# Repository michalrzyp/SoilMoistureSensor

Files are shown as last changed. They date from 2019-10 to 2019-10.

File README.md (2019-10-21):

# SoilMoistureSensor
The assumption of the project was to create a soil moisture sensor and a station collecting measurement results, 
which by analyzing the received data provides information on the degree of soil moisture. 
The sensor placed in the pot sends information via radio to the base station, which is located anywhere in the apartment / house. 
The sensor measured humidity by measuring its resistance.

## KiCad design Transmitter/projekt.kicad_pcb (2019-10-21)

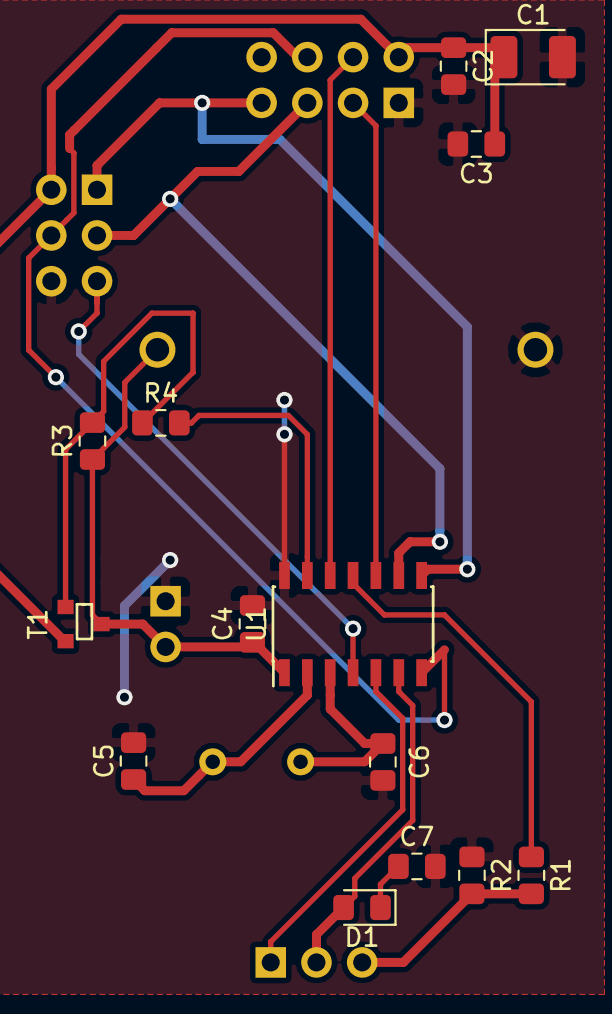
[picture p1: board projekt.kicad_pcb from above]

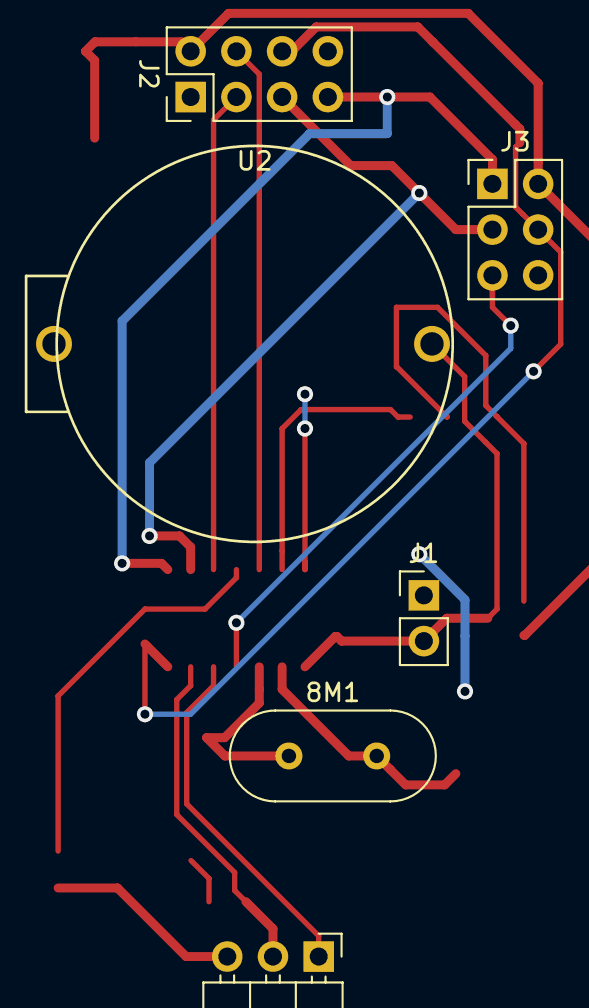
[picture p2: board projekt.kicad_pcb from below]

Board: 2 copper layers, 20 parts (6 on the bottom side), 18 nets.

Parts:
8M1: Crystal_Small; Crystal_HC49-4H_Vertical
C1: 100u; CP_EIA-3528-21_Kemet-B_Pad1.50x2.35mm_HandSolder
C2, C3, C4: 100n; C_0805_2012Metric_Pad1.15x1.40mm_HandSolder
C5, C6, C7: 22p; C_0805_2012Metric_Pad1.15x1.40mm_HandSolder
D1: 1N4148; D_0805_2012Metric_Pad1.15x1.40mm_HandSolder
J1: Conn_01x02; PinHeader_1x02_P2.54mm_Vertical
J2: Conn_02x04_Odd_Even; PinHeader_2x04_P2.54mm_Vertical
J3: AVR-ISP-6; PinHeader_2x03_P2.54mm_Vertical
J4: Conn_01x03; PinHeader_1x03_P2.54mm_Horizontal
R1, R2: 0; R_0805_2012Metric_Pad1.15x1.40mm_HandSolder
R3, R4: R_Small; R_0805_2012Metric_Pad1.15x1.40mm_HandSolder
T1: DMG2305UX; moj
U1: ATtiny84A-SSU; SOIC-14_3.9x8.7mm_P1.27mm
U2: DS1092-04-B6P

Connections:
+3V3: C4.1, J1.2, R3.1, T1.3, U1.1, U2.2
/CE: J2.3, U1.10
/CSN: J2.4, U1.12
/GEN: J4.1, U1.5
/MISO: J2.7, J3.1, U1.8
/MOSI: J2.6, J3.4, U1.7
/SCK: J2.5, J3.3, U1.9
/VCC_R: C1.1, C2.1, C3.1, J2.2, J3.2, T1.2
/ZAS_RADIO: R4.2, U1.13
/czujnik: D1.2, J4.2, U1.6
/pinHL: R1.1, U1.11
/~RESET: J3.5, U1.4
GND: C1.2, C2.2, C3.2, C4.2, C5.2, C6.2, C7.2, J1.1, J2.1, J3.6, R2.1, U1.14, U2.1
unnamed: 8M1.1, C6.1, U1.3
unnamed: 8M1.2, C5.1, U1.2
unnamed: C7.1, D1.1
unnamed: J4.3, R1.2, R2.2
unnamed: R3.2, R4.1, T1.1

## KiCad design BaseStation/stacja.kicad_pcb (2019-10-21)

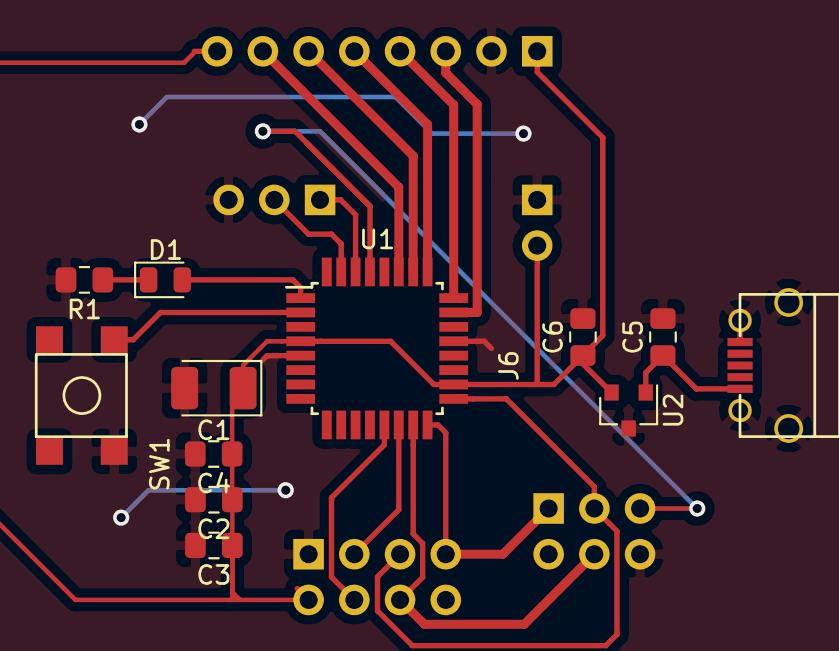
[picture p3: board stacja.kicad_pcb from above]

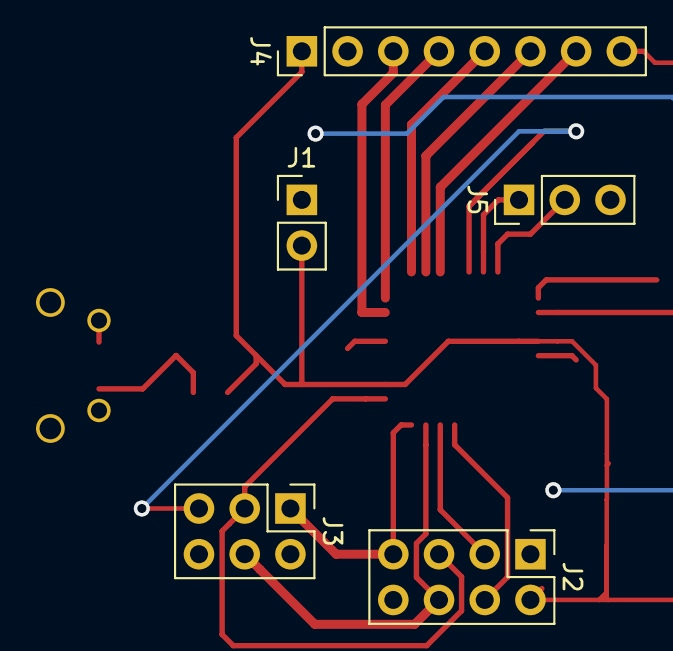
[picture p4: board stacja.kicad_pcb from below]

Board: 2 copper layers, 17 parts (5 on the bottom side), 19 nets.

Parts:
C1: 100u; CP_EIA-3528-21_Kemet-B_Pad1.50x2.35mm_HandSolder
C2, C3, C4: 100n; C_0805_2012Metric_Pad1.15x1.40mm_HandSolder
C5, C6: 1u; C_0805_2012Metric_Pad1.15x1.40mm_HandSolder
D1: LED_Small; LED_0805_2012Metric
J1: Conn_01x02; PinHeader_1x02_P2.54mm_Vertical
J2: Conn_02x04_Odd_Even; PinHeader_2x04_P2.54mm_Vertical
J3: AVR-ISP-6; PinHeader_2x03_P2.54mm_Vertical
J4: Conn_01x08; PinHeader_1x08_P2.54mm_Vertical
J5: Conn_01x03; PinHeader_1x03_P2.54mm_Vertical
J6: USB_B_Micro; microusb
R1: 1k; R_0805_2012Metric_Pad1.15x1.40mm_HandSolder
SW1: SW_Push; button
U1: ATmega328PB-AU; TQFP-32_7x7mm_P0.8mm
U2: AP7333; SOT-23

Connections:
+3V3: C1.1, C2.1, C3.1, C4.1, C6.1, J1.2, J2.2, J4.1, J4.8, U1.4, U1.18, U2.2
/BUTTON1: SW1.1, U1.2
/CE: J2.3, U1.14
/CSN: J2.4, U1.13
/LCD_A0: J4.5, U1.25
/LCD_CS: J4.3, U1.23
/LCD_MOSI: J4.6, U1.26
/LCD_RST: J4.4, U1.24
/LCD_SCK: J4.7, U1.27
/LED: D1.2, U1.1
/MISO: J2.7, J3.1, U1.16
/MOSI: J2.6, J3.4, U1.15
/RX: J5.1, U1.30
/SCK: J2.5, J3.3, U1.17
/TX: J5.2, U1.31
/~RESET: J3.5, U1.29
GND: C1.2, C2.2, C3.2, C4.2, C5.2, C6.2, J1.1, J2.1, J3.6, J4.2, J5.3, J6.5, J6.6, R1.2, SW1.2, U1.5, U1.21, U2.3
unnamed: C5.1, J6.1, U2.1
unnamed: D1.1, R1.1

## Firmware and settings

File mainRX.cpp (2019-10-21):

#include <avr/io.h>
#include <avr/interrupt.h>
#include <avr/wdt.h>
#include "nrf24.h"
#include <util/delay.h>
#include <stdint.h>
#include <string.h>
#include <stdlib.h>
#include <string.h>
#include "ili9163lcd.h"
//#define Vref 3.3

ILI9163 	lcd;
DigitalPin	pinSCK(&PORTC, 4), pinSDA(&PORTC, 3), pinA0(&PORTC, 2), pinRESET(&PORTC, 1), pinCS(&PORTC, 0);

char* make_one (char* one, char* two);
char* int2ASCII(int number);

uint8_t data_array[4] = {0,0,0,0};
uint8_t tx_address[5] = {0xD7,0xD7,0xD7,0xD7,0xD7};
uint8_t rx_address[5] = {0xE7,0xE7,0xE7,0xE7,0xE7};
double Vref=3.3;
int state=512;
//double state_in_mV=0;

int main(void) 
{
	lcd.setup(&pinSCK, &pinSDA, &pinA0, &pinRESET, &pinCS);
	lcd.init(ILI9163::ROT0);
	lcd.clear(rgb24to16(0, 0, 0));

	nrf24_init();
	nrf24_config(5,4);
	nrf24_tx_address(tx_address);
	nrf24_rx_address(rx_address);
	
	DDRD = 1<<3;
	PORTD |=1<<4;
	char *char_pointer1=(char*)"0023 ";
	char *char_pointer2=(char*)"WET ";
	char *char_pointer3=(char*)"0000 \0";
	char* result1;
	
	while(1)
	 {
		if(nrf24_dataReady())
		{
			nrf24_getData(data_array);  
			char_pointer1 = reinterpret_cast<char*>(data_array);
			state=atoi(char_pointer1);
			
			int state_in_mV=((state*Vref*1000))/1024;
			
			if(state>512) {char_pointer2=(char*)"DRY ";}
			else {char_pointer2=(char*)"WET ";}
				
			result1 = make_one((char*)"Result: ", char_pointer1);
			char_pointer3=int2ASCII(state_in_mV);
			
			lcd.drawString(result1, textX(0), textY(7), rgb24to16(0, 0, 0xFF), rgb24to16(0,0,0));
			lcd.drawString(char_pointer2, textX(9), textY(8), rgb24to16(0xFF, 0, 0), rgb24to16(0,0,0));
			
			lcd.drawString((char_pointer3), textX(9), textY(9), rgb24to16(0, 0xFF, 0), rgb24to16(0,0,0));
			
			free(result1);
			
			PORTD |=1<<3;
			_delay_ms(500);
		}
		else if(!(PIND & (1<<4)))
		{
			lcd.clear(rgb24to16(0, 0, 0));
		}
		else
		{
			PORTD &=~(1<<3);
			_delay_ms(500);
		}
	 }
}


char* make_one(char* one, char* two)
{
	unsigned int len = strlen(one) + strlen(two);
	char* con = (char*) malloc(len+1);
	unsigned int i,l;

	for(i=0;i<strlen(one);i++)
	{
		con[i]=one[i];
	}
	unsigned int t=0;
	for(l=strlen(one);l<=len;l++)
	{
		con[l]=two[t];
		t++;
	}
	return con; 
}

char* int2ASCII(int number)
{
	int n=number;
	int power=3;
	static char data[8];
	for(int i=0;i<4;i++)
	{
		power=pow(10,3-i);
		data[i]=((n/power)%10)+48;
	}
	data[4]='m';
	data[5]='V';
	data[6]=' ';
	data[7]='\0';
	return data;
}
